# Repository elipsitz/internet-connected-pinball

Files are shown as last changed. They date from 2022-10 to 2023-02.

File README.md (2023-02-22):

# Internet Connected Pinball

A project to allow Williams System 7 pinball machines to automatically upload scores to a website.

[**Read more about the project here**](https://eli.lipsitz.net/posts/internet-connected-pinball/)

This repository has code and design files for the device that taps into the pinball machine's bus, and the web application that receives and displays the scores.

None of the code here is production quality, it's purely for reference and inspiration. 

## Contents
* `address-decoder`: Program for the ATF16V8 PLD chip, used as an address decoder
* `controller`: Raspberry Pi Pico W controller software
* `testing`: Software written to help test the device during development
* `pcb`: KiCad design files for the PCB
* `web`: Flask webapp showing pinball scores and score upload API
* `obsolete`: Obsolete software: original ESP32-based controller, RP2040 proof of concept

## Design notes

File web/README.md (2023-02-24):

# Score Server

Deployed with `dokku`. 

Set up the `data` directory somewhere, rename the example `config.example.json` to `config.json`, and mount the directory in the app container with:

`dokku storage:mount <app> <location of data directory>:/data`

Deployment of just the `web` subtree to Dokku:

```
git push dokku `git subtree split --prefix web main`:main --force
```

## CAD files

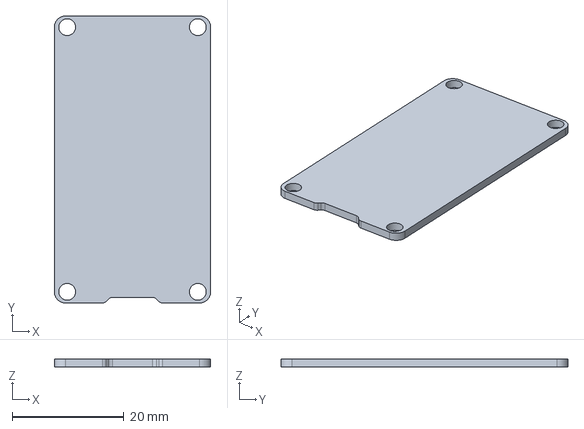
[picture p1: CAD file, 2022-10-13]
pcb/esp32_devkit_v1_doit.step
28.0 x 51.4 x 1.50 mm

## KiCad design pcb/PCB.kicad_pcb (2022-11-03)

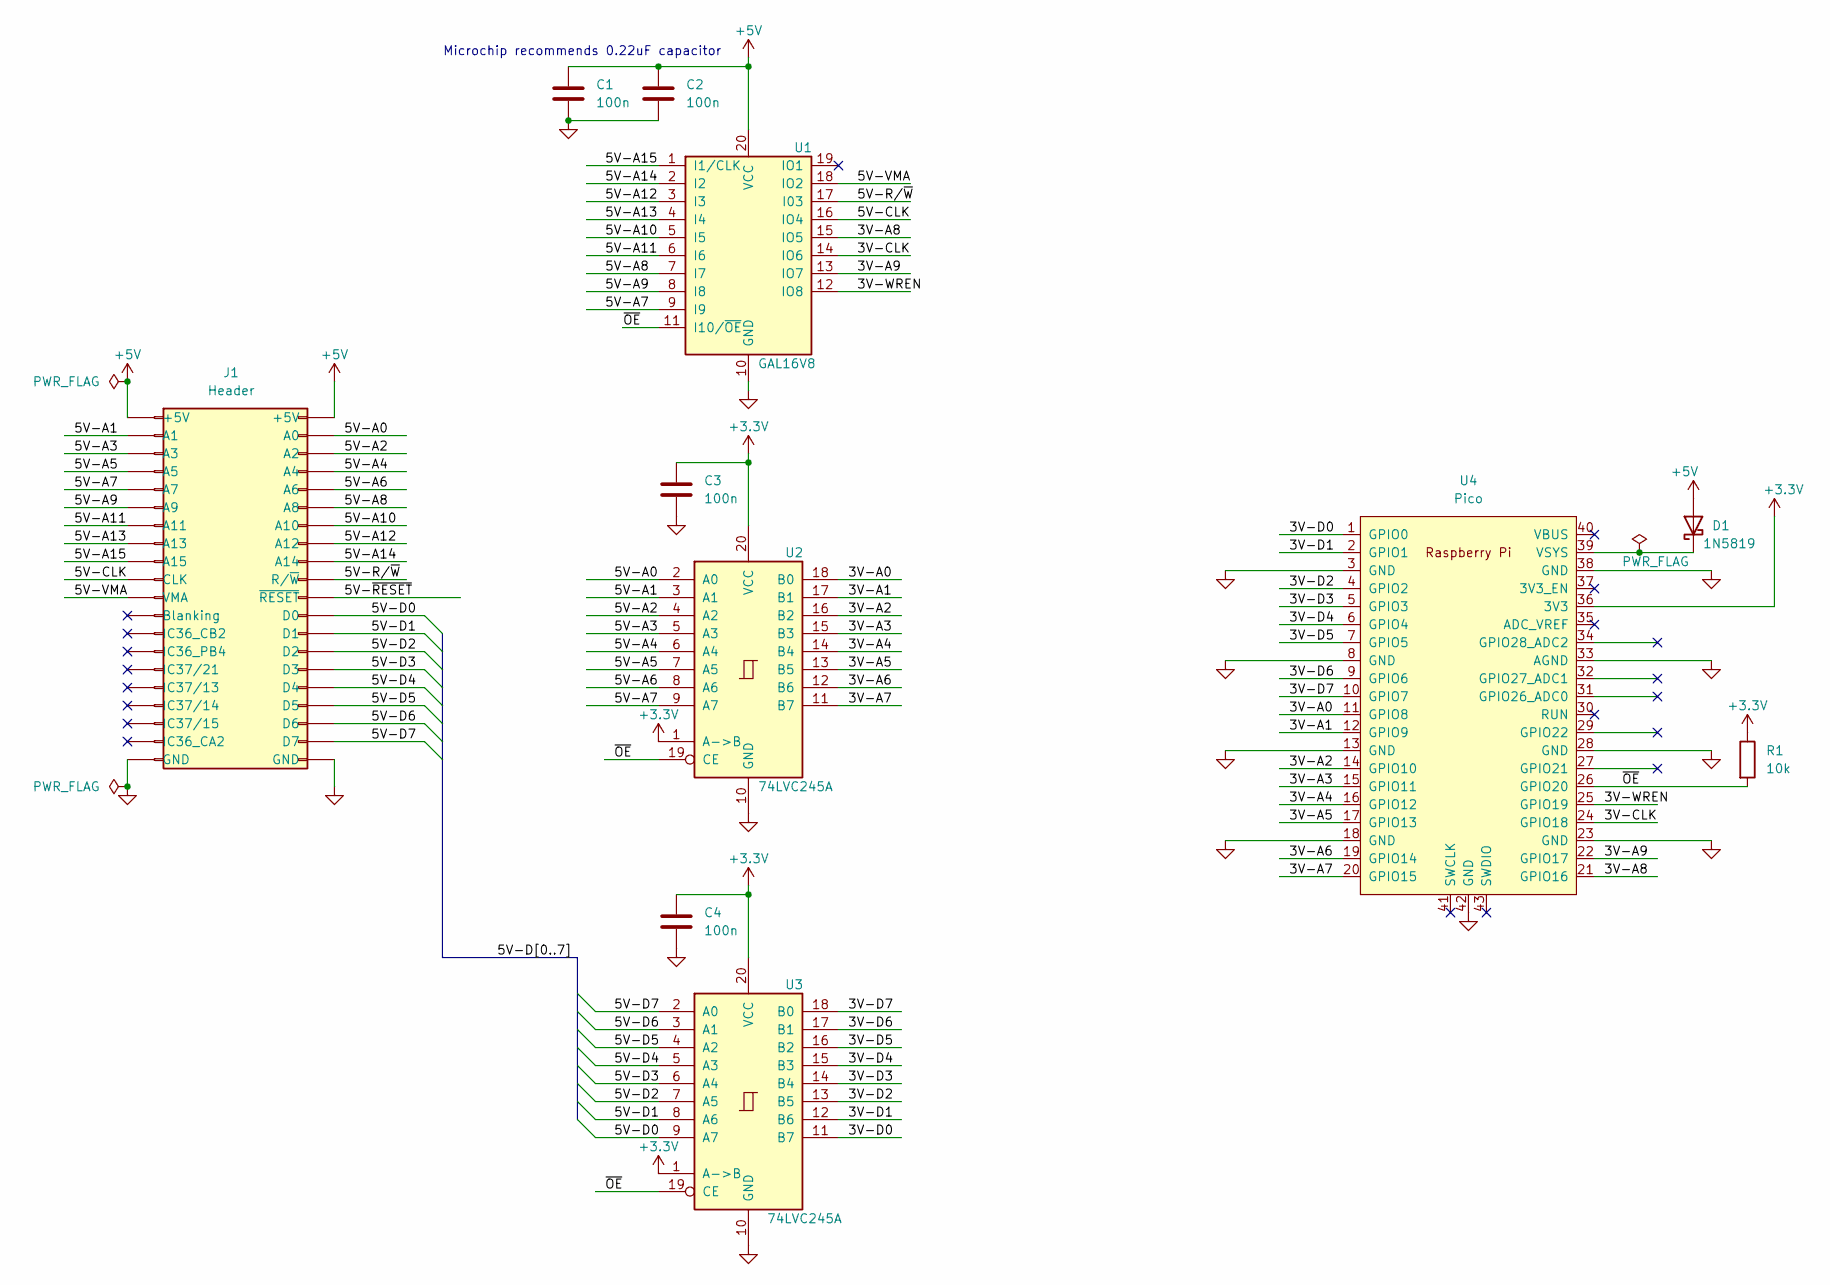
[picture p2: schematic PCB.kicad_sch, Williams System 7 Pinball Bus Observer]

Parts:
C1, C2, C3, C4: 100n; C_Disc_D3.4mm_W2.1mm_P2.50mm
D1: 1N5819; D_DO-41_SOD81_P10.16mm_Horizontal
J1: Header; PinSocket_2x20_P2.54mm_Vertical
R1: 10k; R_Axial_DIN0207_L6.3mm_D2.5mm_P10.16mm_Horizontal
U1: GAL16V8; DIP-20_W7.62mm_Socket
U2, U3: 74LVC245A; DIP-20_W7.62mm
U4: Pico; RPi_PicoW_SMD_TH

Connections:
+3.3V: C3.1, C4.1, R1.1, U2.1 (A->B), U2.20 (VCC), U3.1 (A->B), U3.20 (VCC), U4.36 (3V3)
+5V: C1.1, C2.1, D1.2 (A), J1.1 (+5V), J1.2 (+5V), U1.20 (VCC)
/3V-A0: U2.18 (B0), U4.11 (GPIO8)
/3V-A1: U2.17 (B1), U4.12 (GPIO9)
/3V-A2: U2.16 (B2), U4.14 (GPIO10)
/3V-A3: U2.15 (B3), U4.15 (GPIO11)
/3V-A4: U2.14 (B4), U4.16 (GPIO12)
/3V-A5: U2.13 (B5), U4.17 (GPIO13)
/3V-A6: U2.12 (B6), U4.19 (GPIO14)
/3V-A7: U2.11 (B7), U4.20 (GPIO15)
/3V-A8: U1.15 (IO5), U4.21 (GPIO16)
/3V-A9: U1.13 (IO7), U4.22 (GPIO17)
/3V-CLK: U1.14 (IO6), U4.24 (GPIO18)
/3V-D0: U3.11 (B7), U4.1 (GPIO0)
/3V-D1: U3.12 (B6), U4.2 (GPIO1)
/3V-D2: U3.13 (B5), U4.4 (GPIO2)
/3V-D3: U3.14 (B4), U4.5 (GPIO3)
/3V-D4: U3.15 (B3), U4.6 (GPIO4)
/3V-D5: U3.16 (B2), U4.7 (GPIO5)
/3V-D6: U3.17 (B1), U4.9 (GPIO6)
/3V-D7: U3.18 (B0), U4.10 (GPIO7)
/3V-WREN: U1.12 (IO8), U4.25 (GPIO19)
/5V-A0: J1.4 (A0), U2.2 (A0)
/5V-A1: J1.3 (A1), U2.3 (A1)
/5V-A2: J1.6 (A2), U2.4 (A2)
/5V-A3: J1.5 (A3), U2.5 (A3)
/5V-A4: J1.8 (A4), U2.6 (A4)
/5V-A5: J1.7 (A5), U2.7 (A5)
/5V-A6: J1.10 (A6), U2.8 (A6)
/5V-A7: J1.9 (A7), U1.9 (I9), U2.9 (A7)
/5V-A8: J1.12 (A8), U1.7 (I7)
/5V-A9: J1.11 (A9), U1.8 (I8)
/5V-A10: J1.14 (A10), U1.5 (I5)
/5V-A11: J1.13 (A11), U1.6 (I6)
/5V-A12: J1.16 (A12), U1.3 (I3)
/5V-A13: J1.15 (A13), U1.4 (I4)
/5V-A14: J1.18 (A14), U1.2 (I2)
/5V-A15: J1.17 (A15), U1.1 (I1/CLK)
/5V-CLK: J1.19 (CLK), U1.16 (IO4)
/5V-D0: J1.24 (D0), U3.9 (A7)
/5V-D1: J1.26 (D1), U3.8 (A6)
/5V-D2: J1.28 (D2), U3.7 (A5)
/5V-D3: J1.30 (D3), U3.6 (A4)
/5V-D4: J1.32 (D4), U3.5 (A3)
/5V-D5: J1.34 (D5), U3.4 (A2)
/5V-D6: J1.36 (D6), U3.3 (A1)
/5V-D7: J1.38 (D7), U3.2 (A0)
/5V-R/~W: J1.20 (R/~W), U1.17 (I03)
/5V-VMA: J1.21 (VMA), U1.18 (IO2)
/5V-~RESET: J1.22 (~RESET)
/~OE: R1.2, U1.11 (I10/~OE), U2.19 (CE), U3.19 (CE), U4.26 (GPIO20)
GND: C1.2, C2.2, C3.2, C4.2, J1.39 (GND), J1.40 (GND), U1.10 (GND), U2.10 (GND), U3.10 (GND), U4.3 (GND), U4.8 (GND), U4.13 (GND), U4.18 (GND), U4.23 (GND), U4.28 (GND), U4.33 (AGND), U4.38 (GND), U4.42 (GND)
unnamed: D1.1 (K), U4.39 (VSYS)

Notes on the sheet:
Microchip recommends 0.22uF capacitor

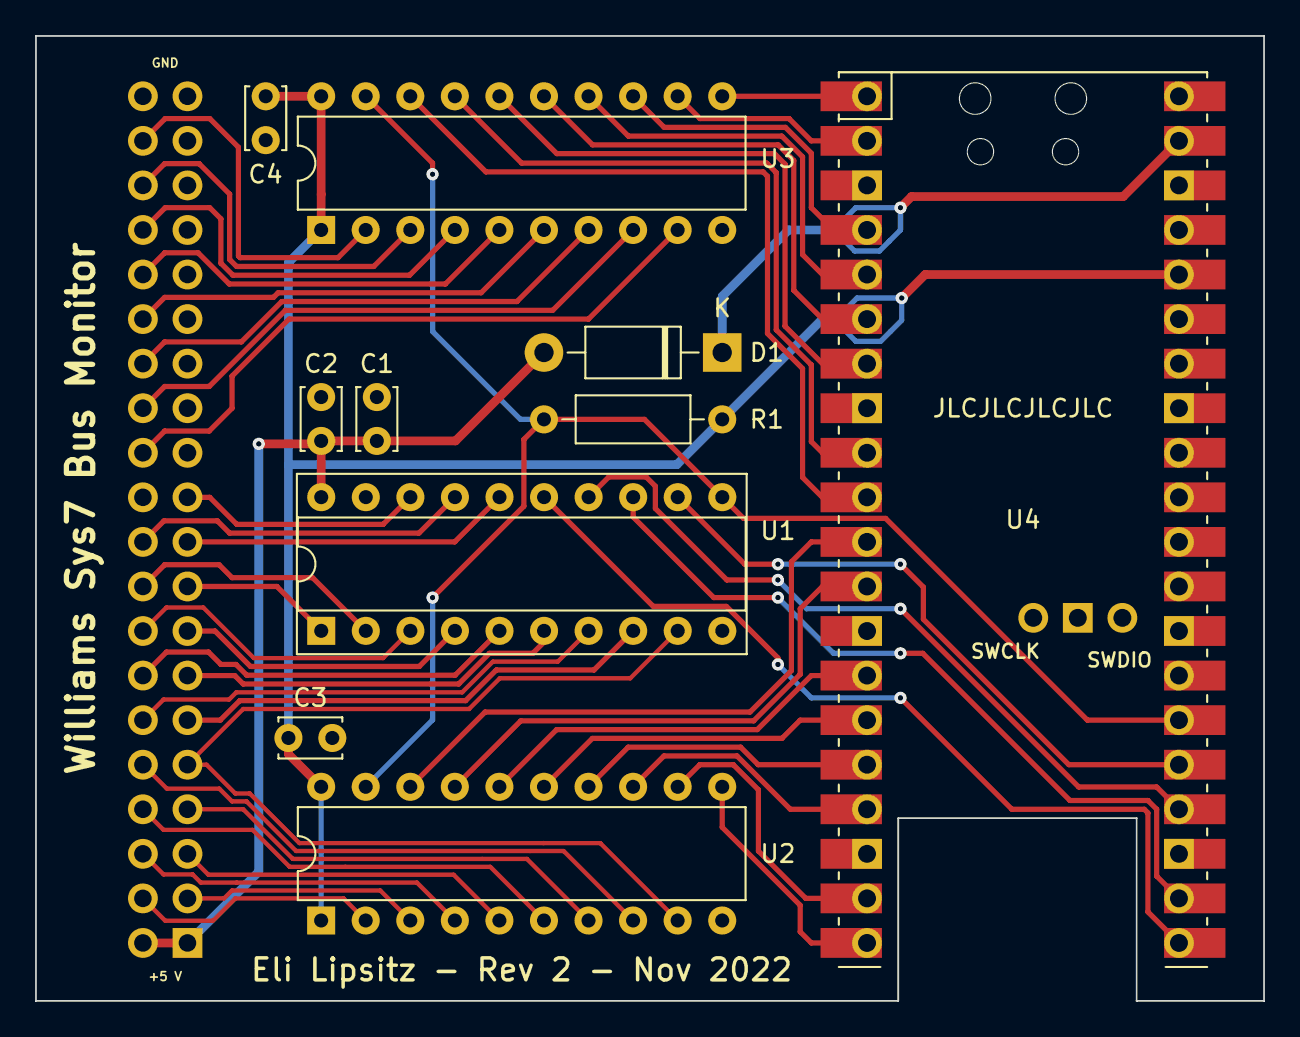
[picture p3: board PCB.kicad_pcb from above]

Board: 2 copper layers, 70.0 x 55.0 mm, 11 parts (1 on the bottom side), 52 nets.

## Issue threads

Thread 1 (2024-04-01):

Wifi and interrupts

frollard, 2024-04-01:
Before replicating this version I had one question: The rp pico w documentation suggests that the IRQ capabilities will be hampered while the WIFI is in use...are you finding that you can transmit while the pio loop is listening to the bus?
https://datasheets.raspberrypi.com/picow/pico-w-datasheet.pdf page 19 regarding spi bus (to wifi module) and the IRQ. In theory from the rp2040 block diagram the pio should be in a league of its own and the irq only applies to the main processor.

We intend to do the same...Our current setup does similar by making a physical shadow copy of the ram, and only doing reads from the shadow copy to prevent a game breaking collision; at worst we corrupt the shadow causing a shadow write miss. Then with our live copy of the data (that we shouldn't read from super often) We combine the scores with an rfid user system that keeps a high score list on the server...I'd like to try your route of using the pico as shadow, and then having the 2nd core handle fun stuff like live commentating the game events to a chat room, controlling other peripherals, etc.
In a flip universe I could see totally emulating the game ram in-situ, such that we could change the machine adjusts/game state live (tap rfid card to build a custom deterministic tournament mode, etc). Much easier to man-in-the-middle the ram if you ARE the ram ;)

elipsitz, 2024-04-02:
I have the pio loop continuously running, and haven't found there to be any issues with WiFi, so I don't think this is a problem.

Reading the datasheet, I believe that line is only talking the IRQ from the wifi chip that's multiplexed over the same pin as spi data in/out, which doesn't affect anything else on the system. All of that communication is all handled by the Pico SDK anyway.

Closed 2024-09-26.

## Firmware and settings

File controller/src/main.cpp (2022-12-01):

#include <Arduino.h>
#include <WiFi.h>
#include <LEAmDNS.h>
#include <pico/cyw43_arch.h>

#include "bus.h"
#include "secrets.h"
#include "ui.h"
#include "game.h"
#include "log.h"

WiFiMulti multi;

#define PING_PERIOD (60 * 1000)
static uint32_t last_ping = 0;

void setup() {
  log_init();
  log_log("main", "Initializing...");
  pinMode(PIN_LED, OUTPUT);
  digitalWrite(PIN_LED, HIGH);

  // Connect to wifi.
  log_log("wifi", "Connecting to %s", CONFIG_WIFI_SSID);
  multi.addAP(CONFIG_WIFI_SSID, CONFIG_WIFI_PASS);
  if (multi.run() != WL_CONNECTED) {
    log_log("wifi", "Unable to connect, rebooting in 10 seconds...");
    delay(10000);
    rp2040.reboot();
  }
  String ip = WiFi.localIP().toString();
  log_log("wifi", "Connected! IP: %s", ip.c_str());

  log_log("mdns", "hostname %s.local", CONFIG_HOSTNAME);
  MDNS.begin(CONFIG_HOSTNAME);
  ui_setup();
  MDNS.addService("http", "tcp", 80);

  game_init();

  digitalWrite(PIN_LED, LOW);
  log_log("main", "Init done");
}

void loop() {
  game_check_state();
  ui_loop();
  MDNS.update();

  // XXX: Hack to keep the WiFi connection active.
  // https://github.com/micropython/micropython/issues/9455 (?)
  if (millis() - last_ping > PING_PERIOD) {
    log_log("wifi", "Pinging server...");
    WiFi.ping(CONFIG_WEB_HOST);
    log_log("wifi", "ping complete.");
    last_ping = millis();
  }

  delay(100);
}

void setup1() {
  bus_run();
}

void loop1() {
}

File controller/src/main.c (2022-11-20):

#include <driver/gpio.h>
#include <esp_event.h>
#include <esp_log.h>
#include <freertos/FreeRTOS.h>
#include <freertos/task.h>
#include <nvs_flash.h>

#include "bus_observer.h"
#include "wifi.h"
#include "ui.h"

// GPIO with the built-in LED.
#define GPIO_LED GPIO_NUM_2

static const char* TAG = "main";

static bus_observer_t DRAM_ATTR bus_observer;

void
app_main(void) {
    ESP_LOGI(TAG, "Initializing");
    ESP_ERROR_CHECK(gpio_reset_pin(GPIO_LED));
    ESP_ERROR_CHECK(gpio_set_direction(GPIO_LED, GPIO_MODE_OUTPUT));
    ESP_ERROR_CHECK(gpio_set_level(GPIO_LED, true));

    // Start the bus observer.
    ESP_LOGI(TAG, "Starting bus observer.");
    int result = bus_observer_start(&bus_observer);
    if (result != 0) {
        ESP_LOGE(TAG, "Error initializing bus observer");
    }

    // Initialize non-volatile storage.
    esp_err_t ret = nvs_flash_init();
    if (ret == ESP_ERR_NVS_NO_FREE_PAGES || ret == ESP_ERR_NVS_NEW_VERSION_FOUND) {
      ESP_ERROR_CHECK(nvs_flash_erase());
      ret = nvs_flash_init();
    }
    ESP_ERROR_CHECK(ret);

    // Start wifi and web UI.
    ESP_ERROR_CHECK(esp_event_loop_create_default());
    wifi_init();
    ui_init(&bus_observer);

    // TODO set up memory poller / HTTP uploader.
    // TODO enable OTA.
    
    // Initialization complete, turn off LED.
    ESP_ERROR_CHECK(gpio_set_level(GPIO_LED, false));
    ESP_LOGI(TAG, "Initialization complete");
    
    uint32_t prev_count = 0;
    while (1) {
        uint32_t new_count = bus_observer.count;
        ESP_LOGI(TAG, "Alive! %d", new_count - prev_count);
        prev_count = new_count;
        vTaskDelay(1000 / portTICK_PERIOD_MS);
    }
}

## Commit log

2022-10-05 Change address decoder to have an output enable pin
2022-10-13 address decoder: move pins around to make PCB routing easier
2022-10-13 Add PCB design files
    [PCB-B_Cu.gbl, PCB-B_Mask.gbs, PCB-B_Paste.gbp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]
2022-10-17 controller: Enable WiFi AP mode on Core 0
    Seems like, to access the SPI Flash, the ESP32 requires doing a
    cross-core function call to disable the SPI cache on the other core.
    This requires interrupts. However, interrupts are disabled on Core 1.
    By reordering some stuff (initializing part of the flash and WiFi before
    starting the core 1 task), and disabling the WiFi PHY calibration
    storage (??), we can make it work and get into Soft-AP mode.
    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
2022-10-30 pcb: create rev2, using raspberry pi pico w
    [PCB.kicad_pcb, PCB.kicad_sch]
2022-10-30 Make pico based controller test
2022-11-03 Finish PCB rev2
    [PCB-B_Cu.gbl, PCB-B_Mask.gbs, PCB-B_Paste.gbp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]
2022-11-20 controller: Add arduino-pico based controller skeleton
2022-11-29 Capture snapshots multiple times per game
    This also makes HTTPS optional for the web interface, temporarily,
    because otherwise requests of >~8KB from the pico-w were timing out.
2022-11-30 Store game data to flash if upload fails
    [main.cpp]
2022-12-19 Flatten directory structure
    [PCB-B_Cu.gbl, PCB-B_Mask.gbs, PCB-B_Paste.gbp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]
2023-02-27 web: Switch column sorting to be server side
2023-02-27 web: switch player name input to bootstrap modal
